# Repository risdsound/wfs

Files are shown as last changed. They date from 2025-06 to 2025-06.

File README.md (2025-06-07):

# Bidirectionally Stacking Loudspeaker Enclosure for Wave Field Synthesis

An open-source, modular loudspeaker enclosure system for Wave Field Synthesis (WFS), developed at the Studio for Research in Sound and Technology (SRST) at Rhode Island School of Design (RISD).

This design supports both classroom and performance applications, and allows users to fabricate enclosures either manually or with a CNC, enabling fabrication across a range of workshop environments.

---

## Overview

This repository contains full open-source designs, hardware files, and documentation for constructing WFS loudspeaker arrays.

The system supports:
- Modular stacking in horizontal and vertical configurations
- 1-tier, 3-tier, and alternate versions
- Easily fabricated parts using standard fabrication tools or CNC
- Adaptability for student projects, research, and live performances

*Note: Alternate versions are provided for experimentation and may not have undergone full acoustic testing.*

---

## Repository Structure

- `/1_tier/` — Files for the single-tier loudspeaker enclosure:
  - `/PDF/` — Full-scale templates for manual cutting (table saw, track saw, drill press, etc.)
  - `/DXF/` — CNC-ready files for digital fabrication
  - `/STL/` — 3D-printable speaker component files (front/back pieces)
  - `/IMAGE/` — Reference build images

- `/3_tier/` — Files for the 3-tier stacked enclosure:
  - Same subfolders: `PDF/`, `DXF/`, `STL/`, `IMAGE/`

- `/alt_version/` — Alternative experimental designs:
  - Same subfolders: `PDF/`, `DXF/`, `STL/`, `IMAGE/`

- `/parts/` — Full Bill of Materials (BOM) for speaker components and cabinet hardware.

---

## Fabrication Methods

**Manual Fabrication**

- Use files in the `PDF` folders.
- Full-scale printouts can be applied directly to the plywood surface.
- Recommended tools: table saw, track saw, drill press, handheld router.

**CNC Fabrication**

- Use files in the `DXF` folders.
- Compatible with standard CAM software and CNC routers/laser cutters.

**3D Printing**

- Use `STL` files to fabricate speaker mounting hardware and front/back enclosures.
- Compatible with standard FDM printers (0.4mm nozzle recommended).

---

## Materials

- **Plywood**: Baltic Birch B/BB grade, 12mm thickness  
  *Note: Baltic Birch is typically supplied in 60" x 60" (1524mm x 1524mm) sheets. Verify sheet dimensions when ordering to ensure cutting layouts are compatible.*

- **Speakers**: 2" Tang Band drivers (T2-2136SG)  
  *Note: The T2-2136SG was custom manufactured to 8 Ohms. It shares the same dimensions as the 4 Ohm T2-2136SF model.*
- **Amplification**: Multi-channel Dante amplifiers (e.g. QSC 16-channel)
- **3D Printing**: STL files provided for speaker unit fabrication
  *Parts were printed using PLA filament on standard FDM printers (0.4mm nozzle recommended).*
- **Hardware Summary**: threaded rods, inserts, banana plugs, fasteners, speaker wiring

> The full hardware Bill of Materials (BOM), including part numbers, quantities, and sourcing information, is provided in the `/parts/` folder as separate cabinet and speaker BOM files. Pricing is not included, as component costs fluctuate over time and based on availability.

---

## Licence

This project is licensed under the CERN Open Hardware Licence Version 2 - Permissive (CERN-OHL-P v2).

You are free to:

- Use
- Modify
- Manufacture
- Distribute

…for any purpose (commercial or non-commercial), provided attribution is maintained and liability is disclaimed.

Full licence text:  
https://ohwr.org/project/cernohl/wikis/Documents/CERN-OHL-version-2

---

## Contributing

We welcome contributions from researchers, students, and educators.

- Please see `CONTRIBUTING.md` for submission guidelines.
- All contributions will be licensed under CERN-OHL-P v2.

---

## Contact

For questions, feedback, or collaboration enquiries, please contact:

**sound@risd.edu**

More information:

- Studio for Research in Sound and Technology (SRST): [SRST](https://sound.risd.edu)
- Rhode Island School of Design: [RISD](https://www.risd.edu)

---

## Authors

- Alex A. Chechile, PhD
- Stephen Cooke
- Will Johnson
- Shawn Greenlee, PhD

---

## Acknowledgements

We would like to thank our Research and Technical Assistants for their help with fabrication and assembly:

- Ada Wu
- Huichun Yang
- Nick Sadler

This work was inspired by the EMPAC system developed at Rensselaer Polytechnic Institute.

Original WFS mathematical models: Berkhout, de Vries, Vogel — *The Journal of the Acoustical Society of America*, 1993.

---

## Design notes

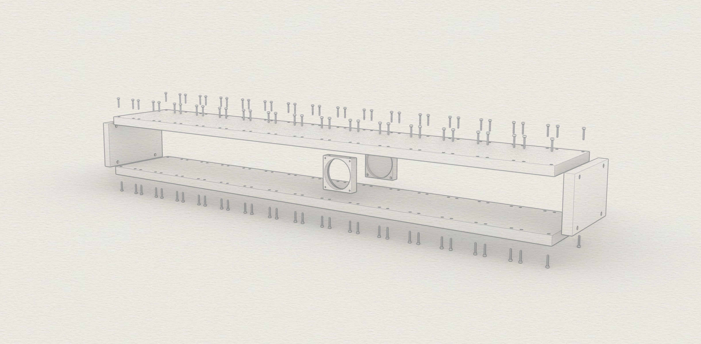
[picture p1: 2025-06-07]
alt_versions/No_Back/IMAGES/1x1_cabinet_exp_alt.jpg

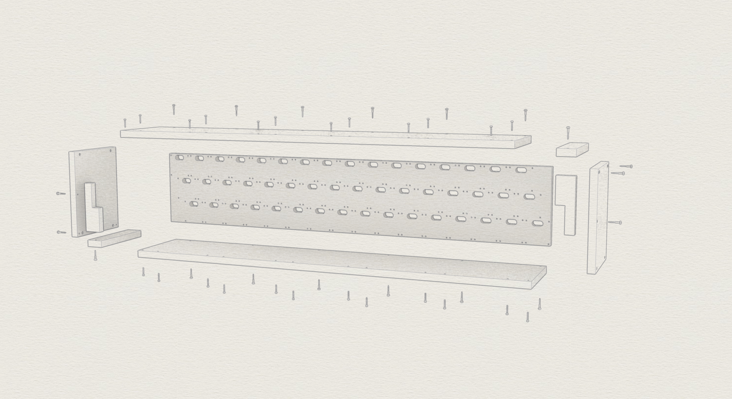
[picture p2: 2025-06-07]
3_tier/IMAGES/3_tier_Cabinet_1x3_exp.jpg

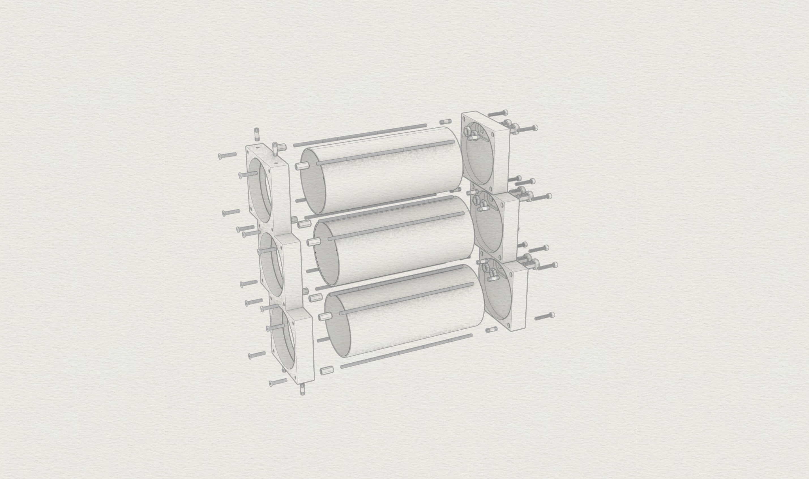
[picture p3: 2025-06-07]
3_tier/IMAGES/3_tier_speaker_Exp.jpg

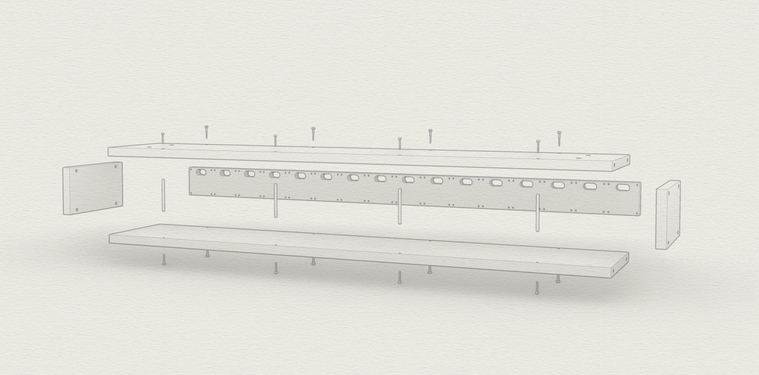
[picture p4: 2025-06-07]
1_tier/IMAGES/speaker_cabinet_1x1_exp.jpg

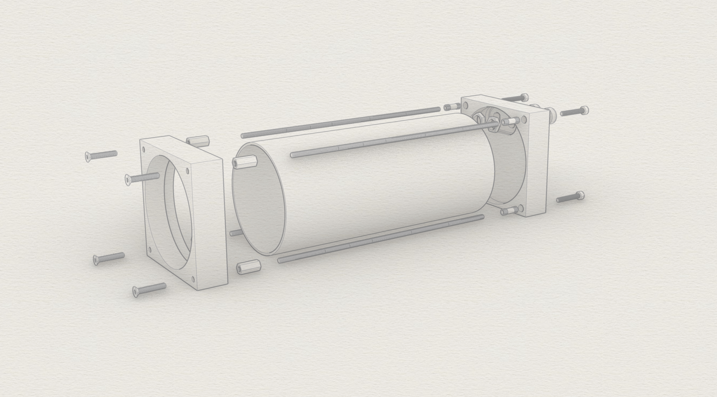
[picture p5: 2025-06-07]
1_tier/IMAGES/Speaker_1x1_exp.jpg

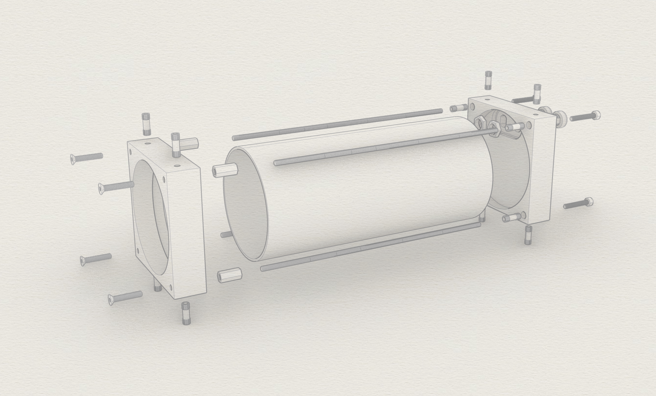
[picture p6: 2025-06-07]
alt_versions/No_Back/IMAGES/1x1_Speaker_exp_alt.jpg

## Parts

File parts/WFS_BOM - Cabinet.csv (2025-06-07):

Speaker Parts List | QTY Cabinet 1-Tier | QTY Cabinet 3-Tier | Vendor link
Descripton |  |  | Link
M3x70mm Round Aluminum Standoff Column Spacer | 5 | 0 | https://www.amazon.com/dp/B09WHM4DP6
Flanged, M6 x 1 mm Thread Size, 10 mm Installed Length | 16 | 16 | https://www.mcmaster.com/95596A205/
M3-0.5 x 20mm Hex Socket Head Cap Screws Bolts, Black Oxide | 74 | 212 | https://www.mcmaster.com/91290A123/
T Shaped Thumb Clamping Screw Knob, M6 x 30mm Metric 304 Stainless Steel | 8 | 8 | https://www.amazon.com/gp/product/B0CP2FYT6Q
T Shaped Thumb Clamping Screw Knob, M6 x 75mm Metric 304 Stainless Steel | 0 | 4 | https://www.amazon.com/gp/product/B0DHPLB3M8
Kreg SPS-F1-100 Zinc Pocket Screws, 1 Inch #6 Fine Thread, Pan Head | 10 | 18 | https://www.amazon.com/Pocket-Hole-Screw-No-6x1-Square-100/dp/B0000DD5GZ

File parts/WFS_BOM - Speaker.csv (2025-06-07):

Speaker Parts List | QTY p/SPK 1-Tier | QTY p/Cab-16 1-Tier | QTY p/SPK 3-Tier | QTY p/Cab-48 3-Tier* | Vendor link
Descripton |  |  |  |  | Link
Tang Band 2" Driver (T2-2136SG)**** | 1 | 16 | 3 | 18 | https://www.parts-express.com/Tang-Band-T2-2136SA-2-Full-Range-Speaker-Module-2-3-4-x-2-3-4-264-938
Molex Dual Row 16CKT Minifit Harness 18AWG 9144mm 30ft***** | - | 1 | 3 | - | https://tools.molex.com/molex/custom-cable-creator/digikey
2.525" I.D. X .060" REX SPEAKER TUBES 6" Spec#: 47432 | 1 | 16 | 3 | 18 | https://www.yazoomills.com/custom-paper-tubes/ **
18/2AWG CCA Red Black 2 Conductor Bonded Stereo Audio Wire | 0.44*** | 7.04*** | 1.32*** | 63.36*** | https://www.amazon.com/gp/product/B0C9V4W3DV
4.8mm Quick Splice Wire Terminals Female Spade Crimp Connector with Insulated Sleeve | 3 | 48 | 9 | 54 | https://www.amazon.com/gp/product/B07XN8SZSP
2.8mm Wire Terminals Connector Quick Splice Female Spade Connect with Insulating Sleeve | 1 | 16 | 3 | 18 | https://www.amazon.com/gp/product/B07XN8SZSP
Black-Oxide Alloy Steel Hex Drive Flat Head Screw 90 Degree Countersink, M3 x 0.50 mm Thread, 20 mm Long | 4 | 64 | 12 | 288 | https://www.mcmaster.com/91294A136/
uxcell Knurled Insert Nuts, 50pcs M3 x 12mm L x 5mm OD | 4 | 64 | 16 | 96 | https://www.amazon.com/dp/B0CTCSXL8Y
M3x150mm Fully Threaded Rod 304 Stainless Steel | 4 | 64 | 12 | 288 | https://www.amazon.com/dp/B0D2MG3PDF
M3x 12mm Female Brass Thread Hex Standoff Spacer | 4 | 64 | 12 | 288 | https://www.amazon.com/dp/B0C2P7K8KV
Banana Plugs, 4mm Gold Plated Screw Type Bannana Plugs | 2 | 32 | 6 | 36 | https://www.amazon.com/dp/B0DTYB83M8
CONN BANANA JACK SOLDER TABS RED | 1 | 16 | 3 | 18 | https://www.digikey.com/en/products/detail/cinch-connectivity-solutions-johnson/108-0902-001/5929
CONN BANANA JACK SOLDER TABS Black | 1 | 16 | 3 | 18 | https://www.digikey.com/en/products/detail/cinch-connectivity-solutions-johnson/108-0903-001/5930
 |  |  |  |  | Notes
 |  |  |  |  | * to Make Six of the supporting speaker rings needed for 3-Tier Cab
 |  |  |  |  | ** Custom length 6"/ 15.2cm OD 6.4cm thickness 2mm
 |  |  |  |  | *** One roll cut into 8" / 20cm length
 |  |  |  |  | **** Custom made for 8ohm contact https://www.tb-speaker.com link in BOM is 4ohm model
 |  |  |  |  | ***** Custom made to amplifier specifications for this application, with specific cable lengths and colour coding

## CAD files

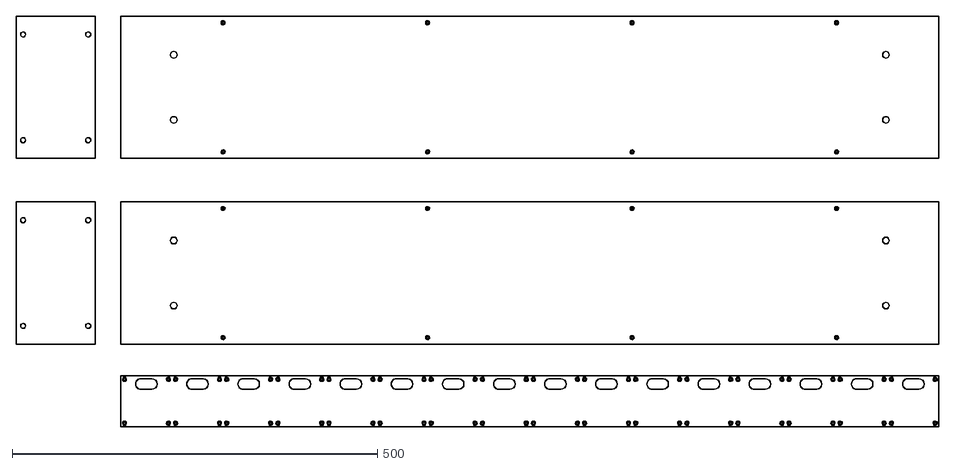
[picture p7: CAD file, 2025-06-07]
1_tier/DXF/1tier_cnc_wfs.dxf
1263.4 x 562.3

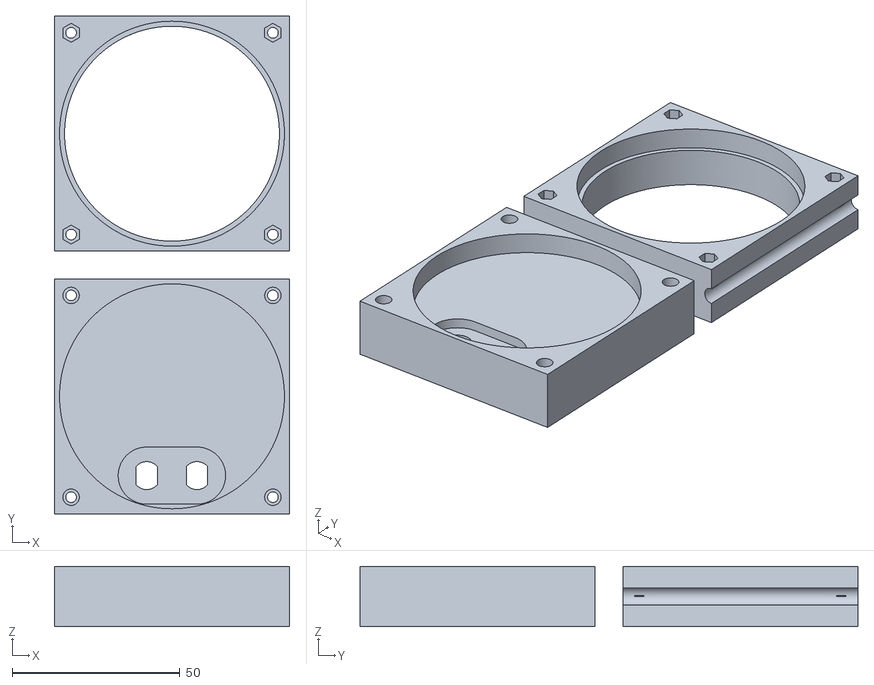
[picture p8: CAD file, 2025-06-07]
1_tier/STL/front_back_combined.stl
70.0 x 148.2 x 18.0

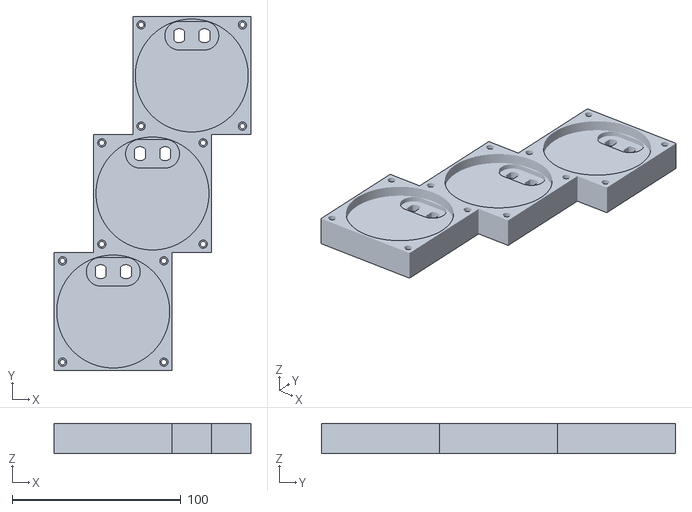
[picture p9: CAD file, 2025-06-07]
3_tier/STL/back.stl
116.6 x 210.0 x 18.0

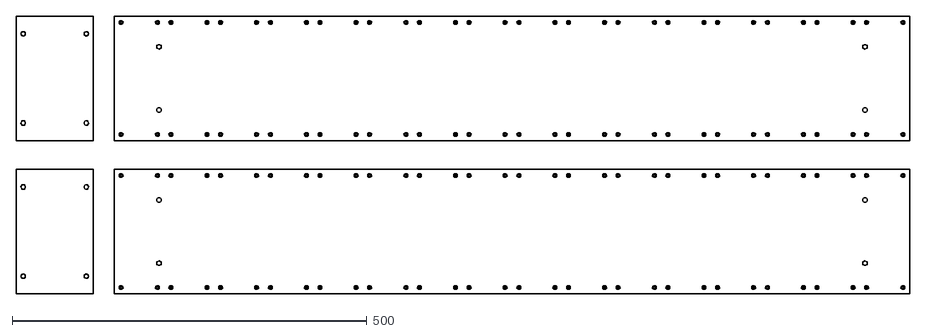
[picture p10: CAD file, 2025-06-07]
alt_versions/No_Back/DXF/1_tier_cnc_wfs.dxf
1258.0 x 391.4

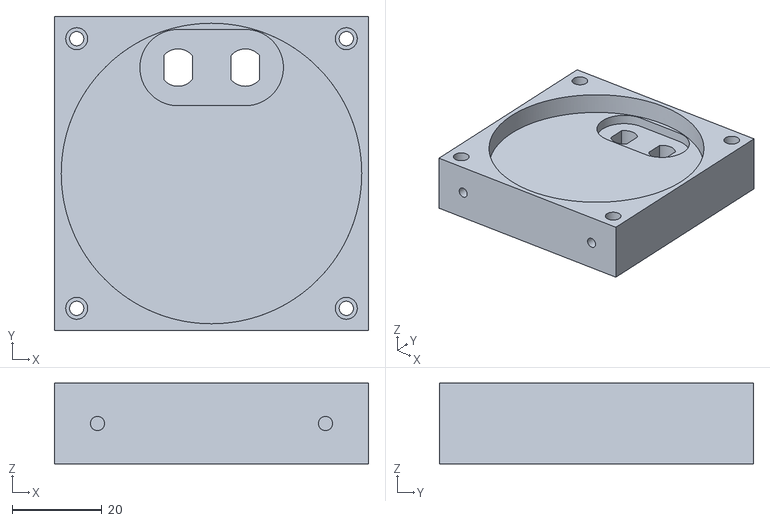
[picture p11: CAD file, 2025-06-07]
alt_versions/No_Back/STL/rear.stl
70.0 x 70.0 x 18.0

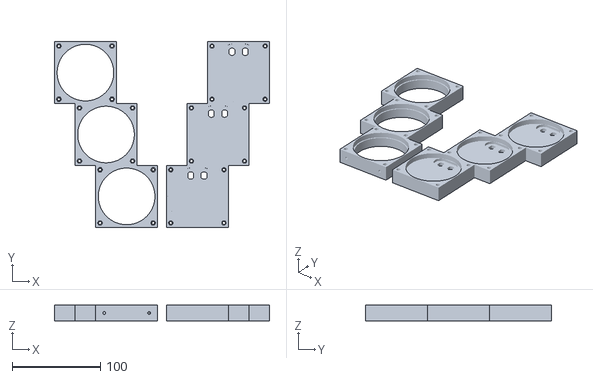
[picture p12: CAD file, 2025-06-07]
3_tier/STL/front_back_combined.stl
243.2 x 210.0 x 18.0

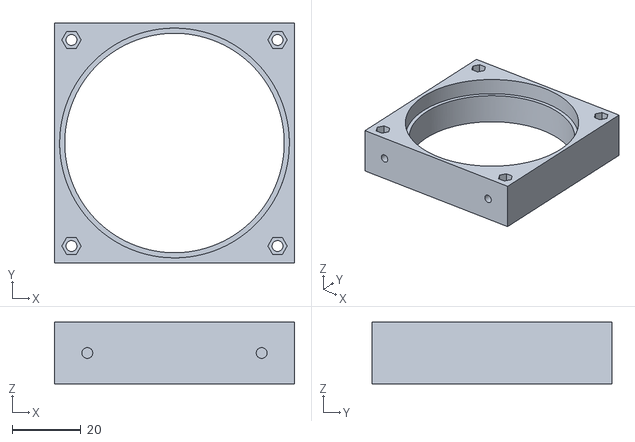
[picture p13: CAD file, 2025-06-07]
alt_versions/No_Back/STL/front.stl
70.0 x 70.0 x 18.0

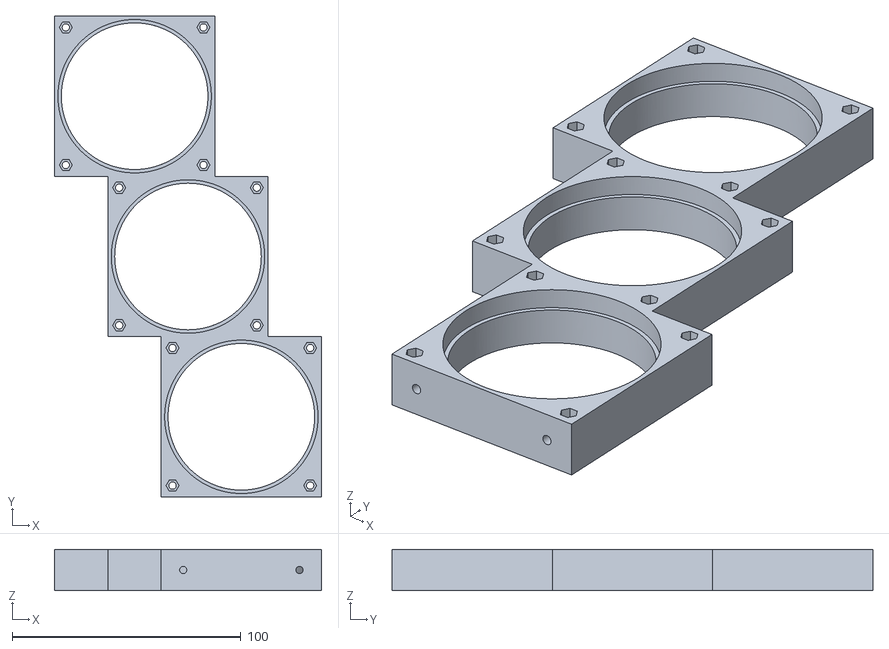
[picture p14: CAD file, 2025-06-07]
3_tier/STL/front.stl
116.6 x 210.0 x 18.0

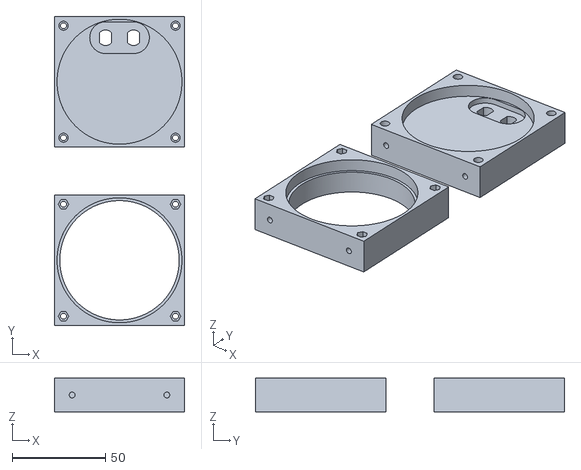
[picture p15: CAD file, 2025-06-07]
alt_versions/No_Back/STL/front_rear_combined.stl
70.0 x 165.8 x 18.0

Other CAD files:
3_tier/DXF/3_tier_CNC.dxf
1_tier/STL/back.stl
1_tier/STL/front.stl

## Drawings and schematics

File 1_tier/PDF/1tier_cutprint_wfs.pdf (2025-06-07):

194.8

194.8

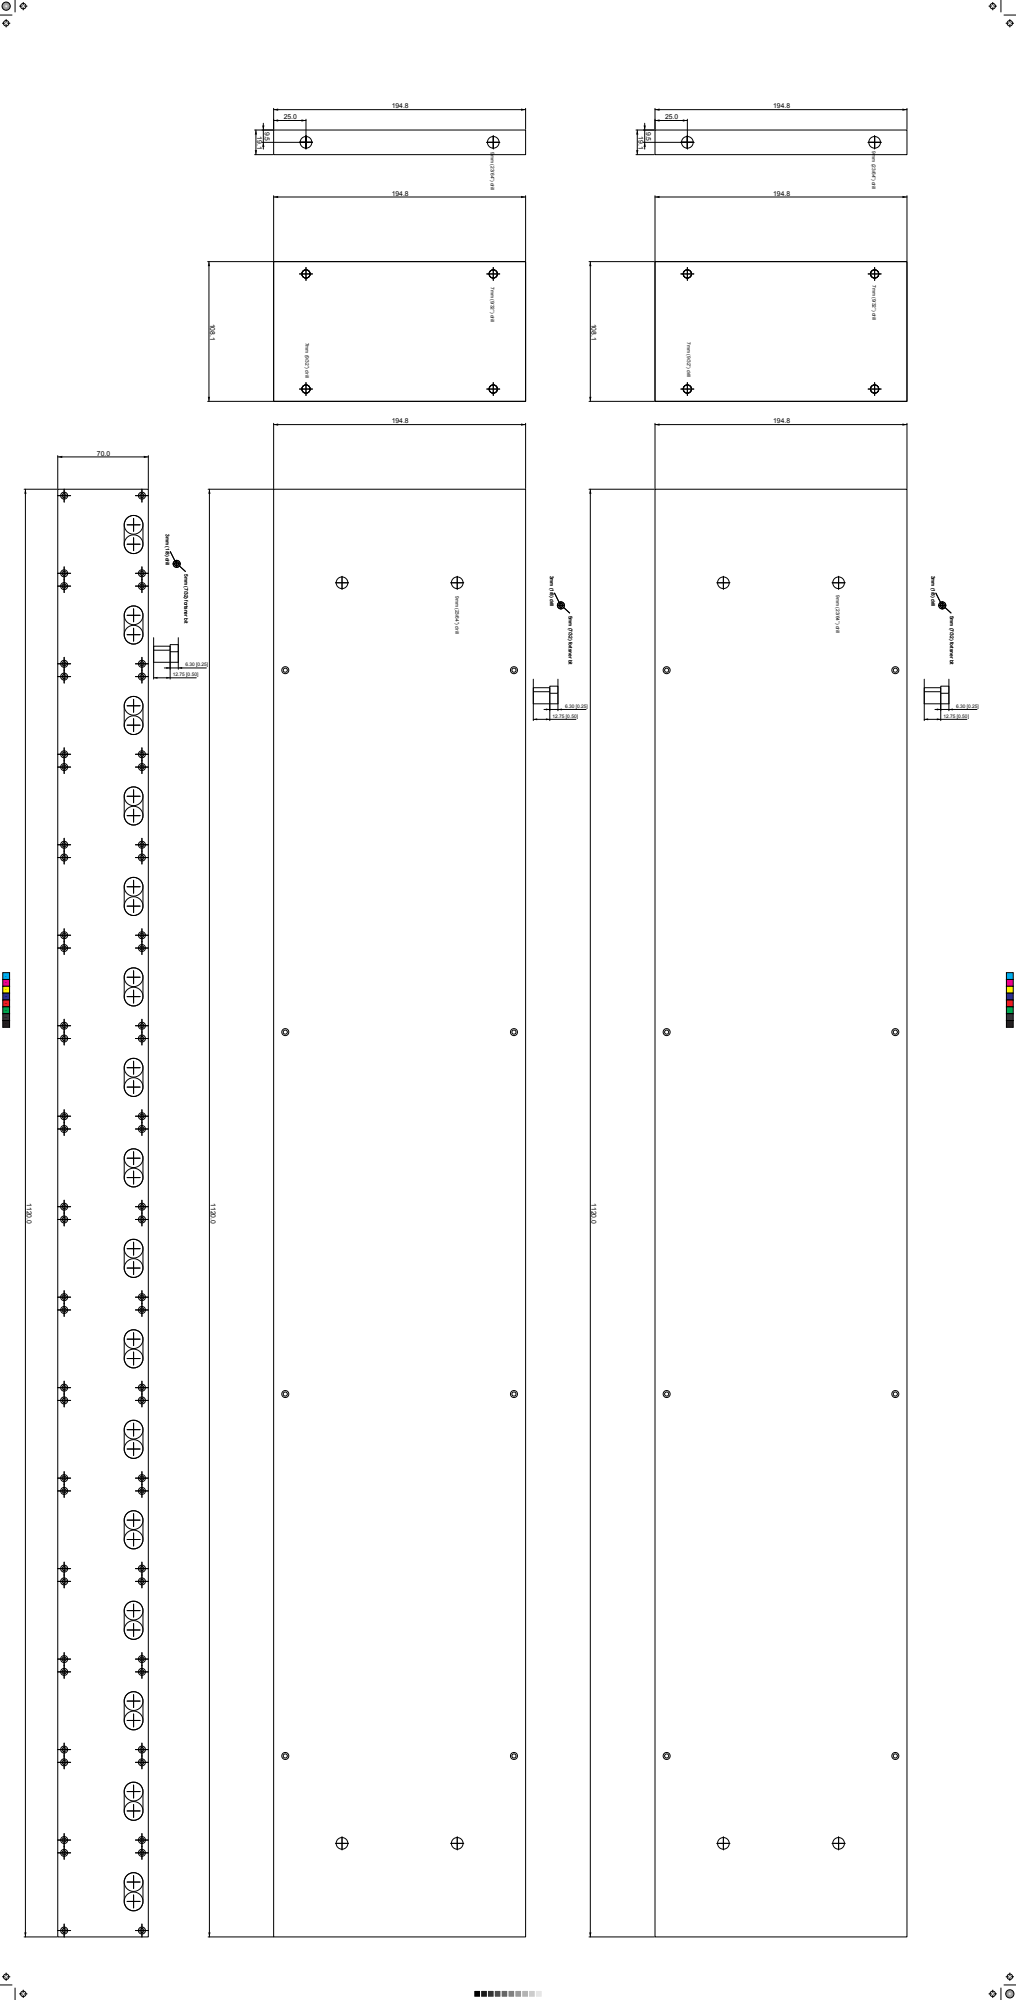
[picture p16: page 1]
7mm (9/32”) drill; 3mm (1/8) drill; 5mm (7/32) fortsner bit; 9mm (23/64”) drill; 9mm (23/64”) drill 7mm (9/32”) drill; CMY; CMYK

3mm (1/8) drill
6.30 [0.25] ⁵mm (7/32) fortsner bit

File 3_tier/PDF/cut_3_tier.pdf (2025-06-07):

## cutline

## cutline

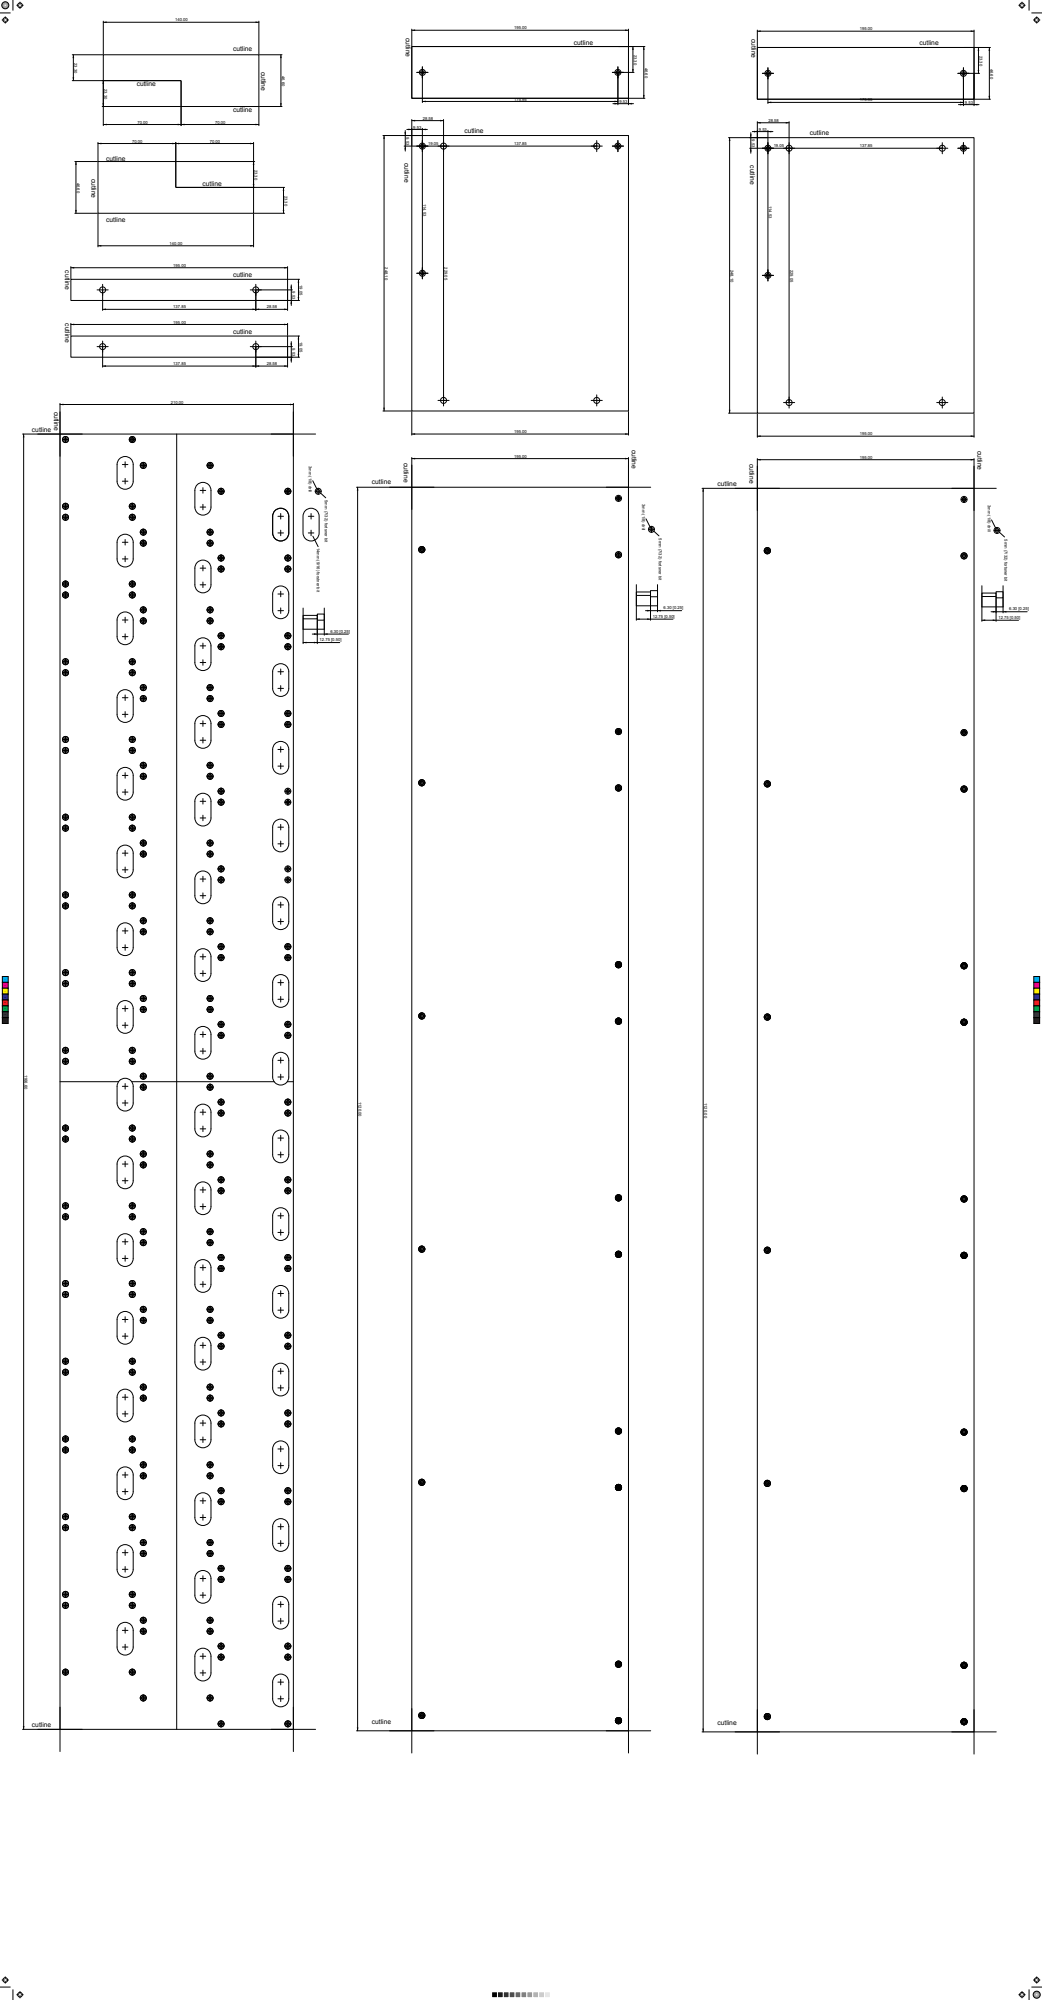
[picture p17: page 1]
cutline; 3mm (1/8) drill; 5mm (7/32) fortsner bit; 14mm (9/16) forstner bit; CMY

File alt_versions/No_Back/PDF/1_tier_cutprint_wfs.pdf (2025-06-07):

175.7

175.7

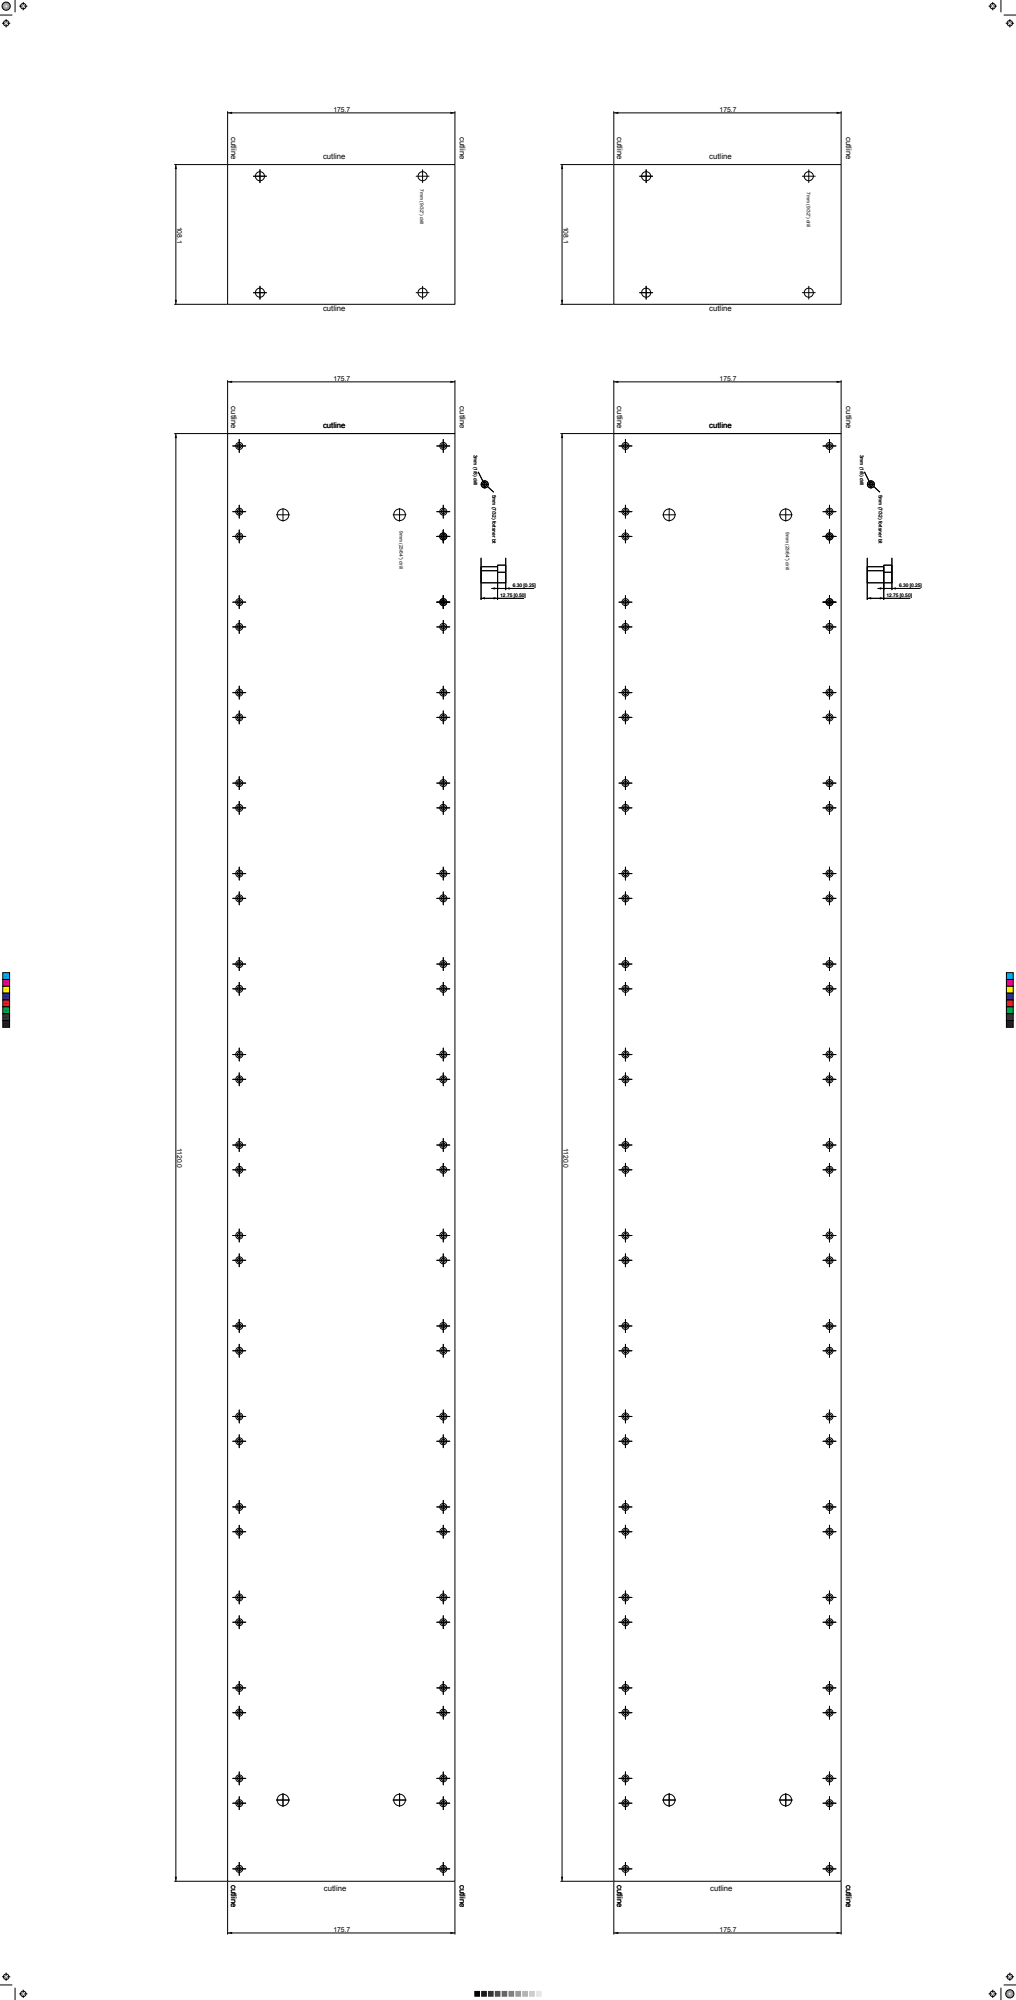
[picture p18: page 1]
cutline; 5mm (7/32) fortsner bit; 3mm (1/8) drill; 7mm (9/32”) drill; 9mm (23/64”) drill; CMY

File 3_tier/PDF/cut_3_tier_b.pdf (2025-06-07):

## cutline cutline

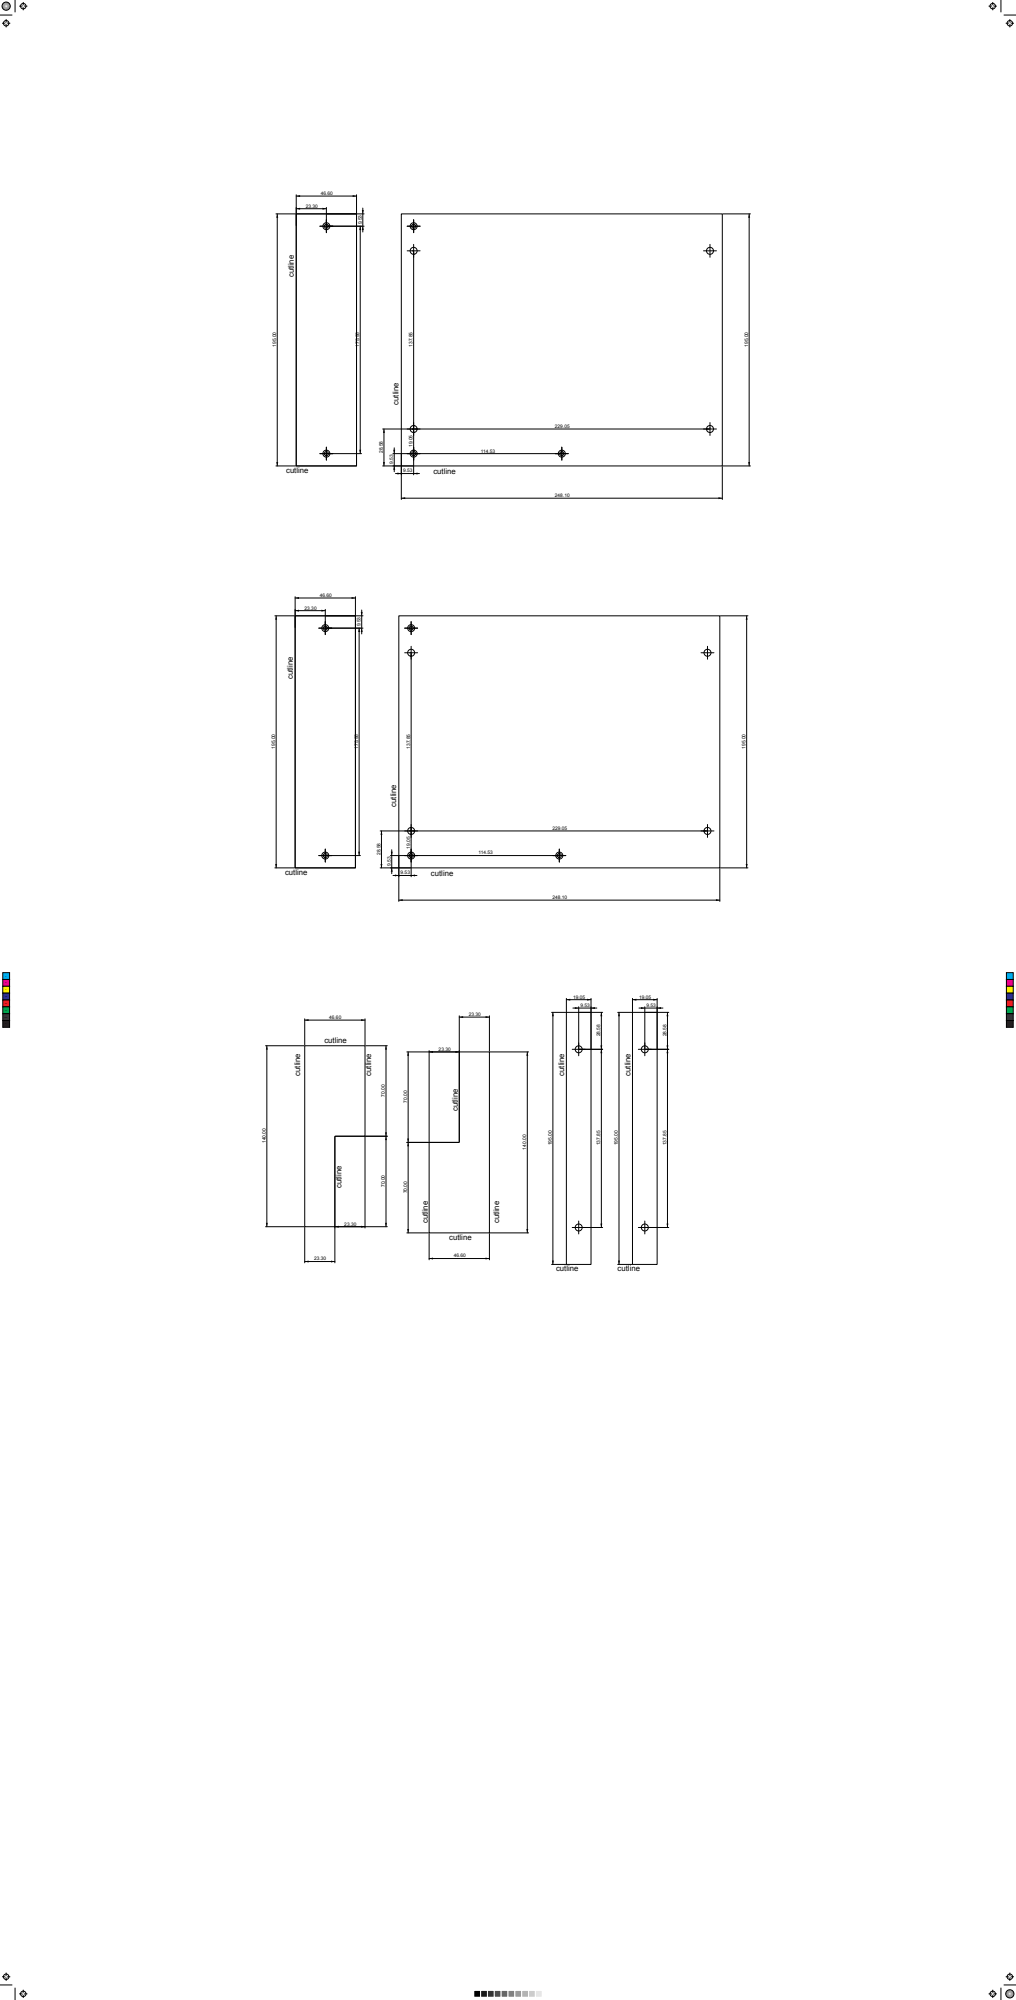
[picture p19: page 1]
cutline; cutline cutline; CMY
